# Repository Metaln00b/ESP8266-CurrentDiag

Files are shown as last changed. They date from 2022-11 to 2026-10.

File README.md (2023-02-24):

# ESP8266-CurrentDiag
ESP8266 (Wemos D1 mini) based Small Current Diagnostic Tool

Measure the current of the electro-hydraulic pressure regulator of a KE-Jetronic

Additionally the lambda value can be measured via the analog input if the gauge has a 5v output. For this, a 180k Ohm resistor must be connected in series before the A0.

I am using the *AFR Wideband Kit from DepoRacing with an OLED 52772WBOLED*

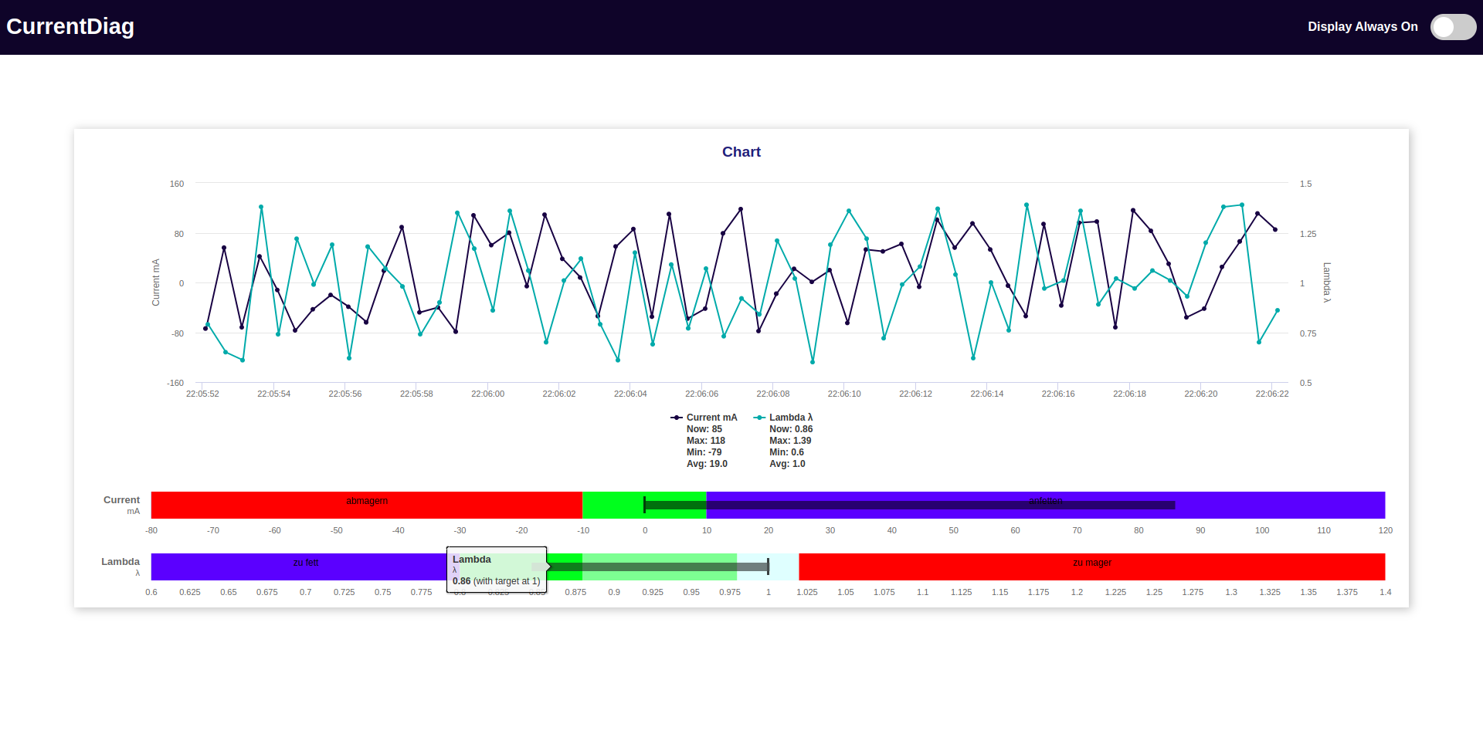
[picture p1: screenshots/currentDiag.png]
Web GUI


Lastly, I added a UDP connection, which transmits the values at a higher update rate, compared to the WebGui. For this I use a RaspberryPi Pico W with an Adafruit library for CircuitPython 8.0.3. The ESP8266 is the server and the Pico W is the client.

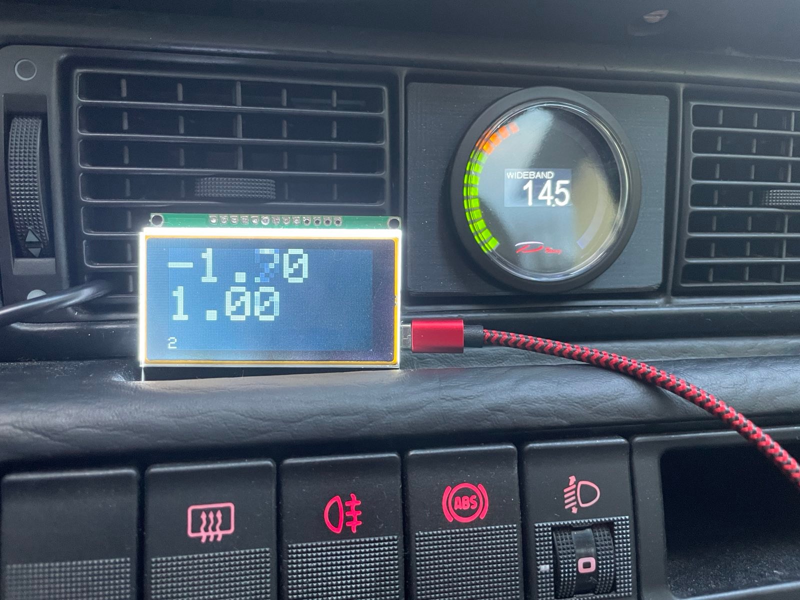
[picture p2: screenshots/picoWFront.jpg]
Pico W UDP Front


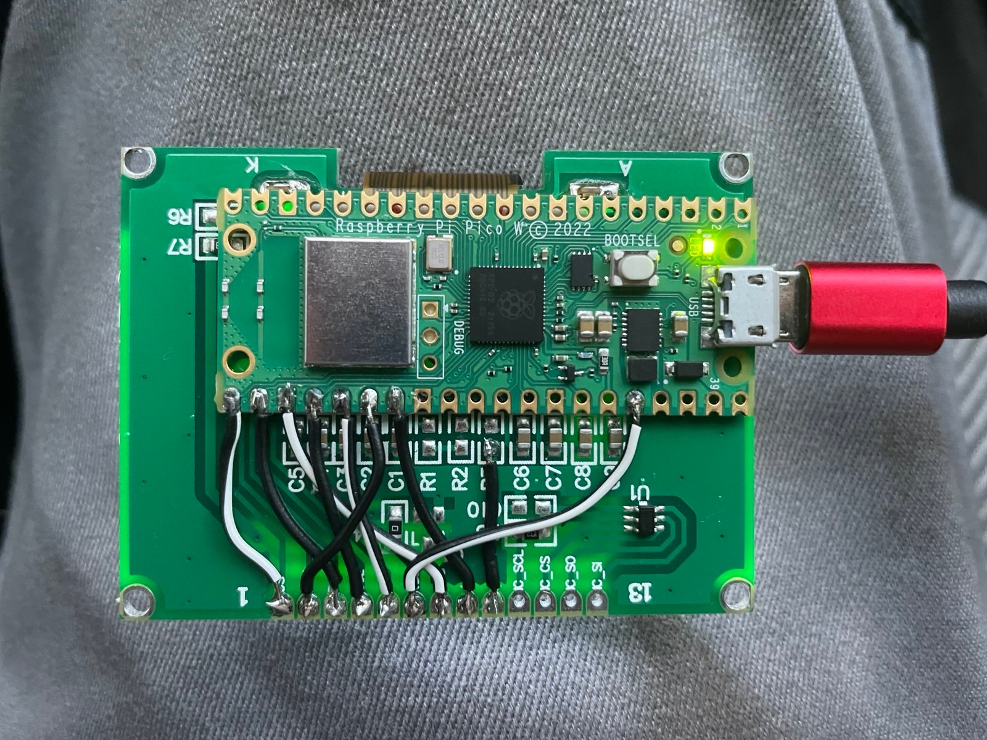
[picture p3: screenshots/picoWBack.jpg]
Pico W UDP Back


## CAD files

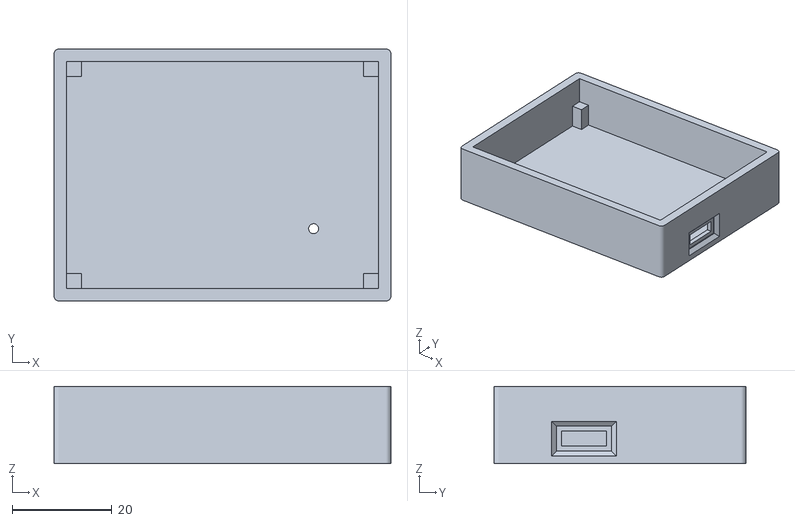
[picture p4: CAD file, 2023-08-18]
pico_w/CAD/CurrentDiag-Body.stl
67.5 x 50.5 x 15.5

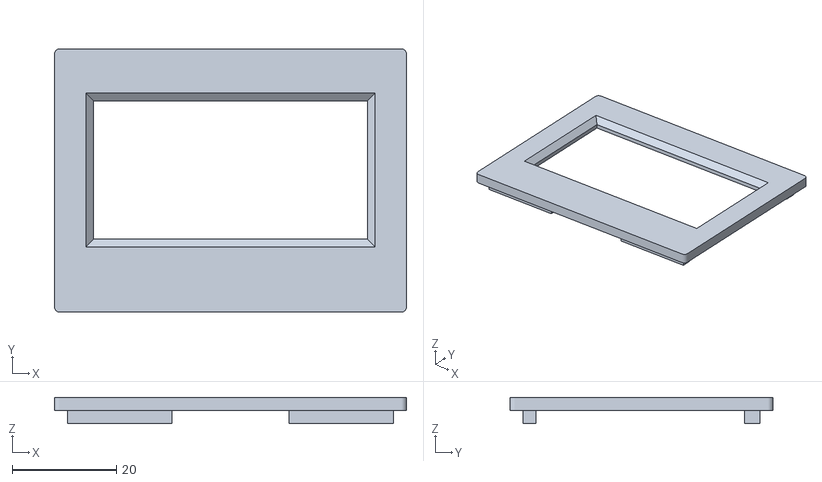
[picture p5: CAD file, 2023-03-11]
pico_w/CAD/CurrentDiag-Front.stl
67.5 x 50.5 x 5.00

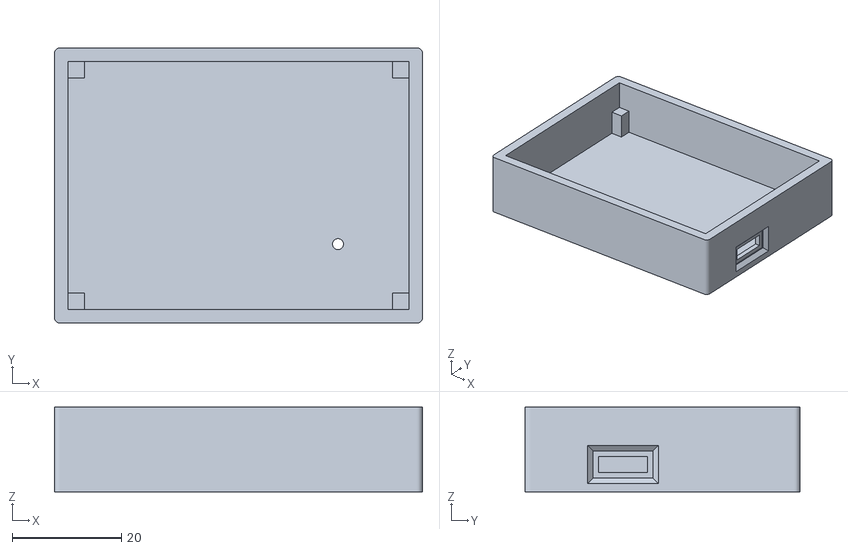
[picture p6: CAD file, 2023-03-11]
pico_w/CAD/CurrentDiag-Body_fixed.stl
67.5 x 50.5 x 15.5

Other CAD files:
pico_w/CAD/CurrentDiag.FCStd

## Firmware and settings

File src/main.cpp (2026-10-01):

#include "Wire.h"
#include "LittleFS.h"
#include "Adafruit_INA219.h"
#include <ESP8266WiFi.h>
#include <ESP8266WiFiAP.h>
#include <ESPAsyncTCP.h>
#include <ESPAsyncWebServer.h>
#include <ArduinoJson.h>
#include <ElegantOTA.h>
#include <WiFiUdp.h>


const char *ssid = "CurrentDiag";
const char *pass = "123456789";

AsyncWebServer server(80);
AsyncEventSource events("/events");

unsigned long lastWebTime = 0;
unsigned long lastUdpTime = 0;
unsigned long lastDataTime = 0;
unsigned long webTimerDelay = 250;
//unsigned long udpTimerDelay = 50;
unsigned long dataTimerDelay = 50;

#ifndef DEBUG
Adafruit_INA219 ina219;
#endif

IPAddress broadcastIP(192, 168, 4, 255);
constexpr uint16_t PORT = 8266;
char packetBuffer[255];
char sensorData[128];

WiFiUDP Udp;

// The ESP8266 SoftAP driver queues broadcast/multicast frames and only
// releases them aligned to its beacon/DTIM interval, regardless of the
// station's own sleep settings - that's what made UDP packets arrive at the
// receiver in ~300ms bursts instead of steadily. Sending unicast to the
// connected stations instead skips that batching. Every station gets its own
// copy, so several displays work at the same time. Falls back to broadcast
// until a station has actually connected.
constexpr uint8_t MAX_RECEIVERS = 4; // SoftAP station limit
IPAddress receivers[MAX_RECEIVERS];
volatile uint8_t receiverCount = 0;

// Samples collected since the last web event, e.g. "[1.00,0.90],[2.00,0.91],"
// The browser gets them in one batch so the chart keeps full resolution
// while it only has to redraw a few times per second.
constexpr size_t BATCH_SIZE = 640;
char webBatch[BATCH_SIZE];
size_t webBatchLen = 0;

void getSensorReadings(char *output, size_t outputSize)
{
    StaticJsonDocument<64> readings;
#ifndef DEBUG
    float current_mA = ina219.getCurrent_mA();
    // Values from afr gauge documentation
    // minLambda = 0.683 (and offset)
    // maxLambda = 1.356
    // lambdaRange = 0.673
    // adcRange = 1024 (0 - 5V with 180k resistor) 0.0049/V
    // 0.673 / 1024 = 0.000657227
    float lambda = ((analogRead(A0) * 0.000657227) + 0.683);
#else
    // Endless cycle: full min -> max -> min sweep, then 5s of random values
    constexpr float CURRENT_MIN = -80.0, CURRENT_MAX = 120.0;
    constexpr float LAMBDA_MIN = 0.6, LAMBDA_MAX = 1.3;
    constexpr unsigned long SWEEP_MS = 20000;
    constexpr unsigned long RANDOM_MS = 5000;
    static bool sweeping = true;
    static unsigned long phaseStart = millis();

    unsigned long elapsed = millis() - phaseStart;
    float current_mA;
    float lambda;

    if (sweeping)
    {
        if (elapsed >= SWEEP_MS)
        {
            sweeping = false;
            phaseStart = millis();
        }
        float frac = (elapsed >= SWEEP_MS) ? 1.0 : (float)elapsed / SWEEP_MS;
        float tri = (frac < 0.5) ? frac * 2.0 : (1.0 - frac) * 2.0; // 0 -> 1 -> 0
        current_mA = CURRENT_MIN + tri * (CURRENT_MAX - CURRENT_MIN);
        lambda = LAMBDA_MIN + tri * (LAMBDA_MAX - LAMBDA_MIN);
    }
    else
    {
        if (elapsed >= RANDOM_MS)
        {
            sweeping = true;
            phaseStart = millis();
        }
        current_mA = random(-80, 120);
        lambda = random(6, 14) / 10.0;
    }
#endif
    char sensor1ValueStr[10];
    char sensor2ValueStr[10];
    dtostrf(current_mA, 6, 2, sensor1ValueStr);
    dtostrf(lambda, 3, 2, sensor2ValueStr);

    readings["sensor1"] = sensor1ValueStr;
    readings["sensor2"] = sensor2ValueStr;

    serializeJson(readings, output, outputSize);

    // Append to web batch, drop the sample if the browser isn't keeping up
    int n = snprintf(webBatch + webBatchLen, BATCH_SIZE - webBatchLen, "[%s,%s],",
                     sensor1ValueStr, sensor2ValueStr);
    if (n > 0 && webBatchLen + n < BATCH_SIZE)
        webBatchLen += n;
}

void sendUdp(const char *data)
{
    uint8_t count = receiverCount;
    if (count == 0)
    {
        Udp.beginPacket(broadcastIP, PORT);
        Udp.print(data);
        Udp.endPacket();
        return;
    }

    for (uint8_t i = 0; i < count; i++)
    {
        Udp.beginPacket(receivers[i], PORT);
        Udp.print(data);
        Udp.endPacket();
    }
}

void initLittleFS()
{
    if (!LittleFS.begin())
    {
        Serial.println(F("An error has occurred while mounting LittleFS"));
    }
    else
    {
        Serial.println(F("LittleFS mounted successfully"));
    }
}

void showClients()
{
    unsigned char number_client;
    struct station_info *stat_info;

    struct ip4_addr *IPaddress;
    IPAddress address;
    int cnt = 1;

    number_client = wifi_softap_get_station_num();
    stat_info = wifi_softap_get_station_info();

    Serial.print(F("Connected clients: "));
    Serial.println(number_client);

    uint8_t count = 0;

    while (stat_info != NULL)
    {
        IPaddress = &stat_info->ip;
        address = IPaddress->addr;

        if (count < MAX_RECEIVERS)
            receivers[count++] = address;

        Serial.print(cnt);
        Serial.print(F(": IP: "));
        Serial.print((address));
        Serial.print(F(" MAC: "));

        uint8_t *p = stat_info->bssid;
        Serial.printf("%02X:%02X:%02X:%02X:%02X:%02X", p[0], p[1], p[2], p[3], p[4], p[5]);

        stat_info = STAILQ_NEXT(stat_info, next);
        cnt++;
        Serial.println();
    }

    receiverCount = count;
    wifi_softap_free_station_info(); // list is allocated by the SDK
}

void eventCb(System_Event_t *evt)
{
    switch (evt->event)
    {
    case WIFI_EVENT_SOFTAPMODE_DISTRIBUTE_STA_IP:
    case WIFI_EVENT_SOFTAPMODE_STADISCONNECTED:
        showClients();
        break;

    default:
        break;
    }
}

void initWiFi()
{
    Serial.println(F("Setting soft-AP ... "));
    wifi_set_event_handler_cb(eventCb);

    IPAddress apIP(192, 168, 4, 1);

    if (WiFi.softAPConfig(apIP, apIP, IPAddress(255, 255, 255, 0)))
        Serial.println(F("softAPConfig: True"));
    else
        Serial.println(F("softAPConfig: False"));

    if (WiFi.softAP(ssid, pass, 8))
        Serial.println(F("softAP: True"));
    else
        Serial.println(F("softAP: False"));

    IPAddress IP = WiFi.softAPIP();
    Serial.print(F("AP IP address: "));
    Serial.println(IP);
}

void setup()
{
    Serial.begin(115200);
    while (!Serial)
    {
        ; // Needed for native USB port only
    }
#ifndef DEBUG
    if (!ina219.begin())
    {
        Serial.println(F("Failed to find INA219 chip"));
    }
#endif

    initWiFi();
    initLittleFS();

    server.on("/", HTTP_GET, [](AsyncWebServerRequest *request)
              { request->send(LittleFS, "/index.html", "text/html"); });

    server.serveStatic("/", LittleFS, "/");

    events.onConnect([](AsyncEventSourceClient *client)
                     {
    if (client->lastId())
    {
      Serial.printf("Client reconnected! Last message ID that it got is: %u\n", client->lastId());
    }
    // send event with message "hello!", id current millis
    // and set reconnect delay to 1 second
    client->send("Hello!", NULL, millis(), 1000);
    Serial.println("Client connected!"); });

    server.addHandler(&events);

    ElegantOTA.begin(&server);

    server.begin();

    Udp.begin(PORT);

    getSensorReadings(sensorData, sizeof(sensorData));
}

void loop()
{
    unsigned long currentMillis = millis();

    if ((currentMillis - lastDataTime) > dataTimerDelay)
    {
        getSensorReadings(sensorData, sizeof(sensorData));
        sendUdp(sensorData);
        lastDataTime += dataTimerDelay;
    }

    if ((currentMillis - lastWebTime) > webTimerDelay)
    {
        // Skip the batch when the browsers can't keep up or the heap is low,
        // instead of piling up queued messages
        if (events.count() > 0 && webBatchLen > 0 && events.avgPacketsWaiting() < 4 && ESP.getFreeHeap() > 8000)
        {
            webBatch[webBatchLen - 1] = '\0'; // strip trailing comma
            char payload[BATCH_SIZE + 40];
            snprintf(payload, sizeof(payload), "{\"dt\":%lu,\"d\":[%s]}", dataTimerDelay, webBatch);
            events.send(payload, "new_readings", millis());
        }
        webBatchLen = 0;
        lastWebTime += webTimerDelay;
    }

    /* if ((currentMillis - lastUdpTime) > udpTimerDelay) {
      sendUdp(sensorData);
      lastUdpTime += udpTimerDelay;
    } */
    ElegantOTA.loop();

    yield();
}

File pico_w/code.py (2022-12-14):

# SPDX-FileCopyrightText: 2021 ladyada for Adafruit Industries
# SPDX-FileCopyrightText: 2021 Mark Olsson <mark@markolsson.se>
# SPDX-License-Identifier: MIT

import microcontroller
import board
import busio
import digitalio
import json
import socketpool
from st7565 import ST7565
import time
import wifi

EXDURATION = 2
TIMEOUT = 2
PORT = 8266

led_onboard = digitalio.DigitalInOut(board.LED)
led_onboard.direction = digitalio.Direction.OUTPUT

# Turn on the Backlight LED
backlight = digitalio.DigitalInOut(board.GP21)  # backlight
backlight.switch_to_output()
backlight.value = True

# Initialize SPI bus and control pins
spi = busio.SPI(clock=board.GP18, MOSI=board.GP19)
dc = digitalio.DigitalInOut(board.GP17)  # data/command
cs = digitalio.DigitalInOut(board.GP16)  # Chip select
reset = digitalio.DigitalInOut(board.GP20)  # reset

display = ST7565(spi, dc, cs, reset)
display.contrast = 3

reconnectCount = 0
heartBeat = True

v1Min = -80
v1Max = 120
v1Vline = 0

v2Min = 0.6
v2Max = 1.4
v2Vline = 1.0

def wrap(string, max_width):
    s=''
    for i in range(0,len(string),max_width):
        s+=string[i:i+max_width]
        s+='\n'
    return s

def printDisplay(string, duration_s):
    display.fill(0)
    display.text(wrap(string, 20), 0, 0, 1)
    display.show()
    time.sleep(duration_s)

def connectWifi():
    while True:
        try:
            wifi.radio.connect("CurrentDiag", "123456789")
            break
        except Exception as e:
            if (str(e) == "Unbekannter Fehler 1" ):
                microcontroller.reset()
            printDisplay(str(e), EXDURATION)

def drawValuebar(x, y, width, height, valueMin, valueMax, value, vlineValue, showNumbers):
    roundValue = round(value, 2)
    roundValue = max(min(valueMax, roundValue), valueMin)

    valueRange = valueMax - valueMin
    pxPerValue = (width - 4) / valueRange
    pxPositionVline = int(pxPerValue * (vlineValue - valueMin) + 2)
    
    pxPositionValue = int(pxPerValue * (roundValue - valueMin) + 2)
    start = min(pxPositionValue, pxPositionVline)
    end = max(pxPositionValue, pxPositionVline)

    display.rect(x, y, width, height, 1)
    display.fill_rect(x+start, y+2, end-start, height-4, 1) 
    
    if (height >= 15 and showNumbers):
        if (value >= vlineValue):
            display.text(str(f"{roundValue:.2f}"), int(width/9), y+5, 1, size=1)
        else:
            display.text(str(f"{roundValue:.2f}"), int(width/1.5), y+5, 1, size=1)
        
    display.vline(int(pxPositionVline), y-1, height+2, 1)

printDisplay("Connecting to wifi", 1)
connectWifi()

pool = socketpool.SocketPool(wifi.radio)
buff = bytearray(255)

printDisplay("Creating socket", 1)
socket = pool.socket(pool.AF_INET, pool.SOCK_DGRAM)
socket.settimeout(TIMEOUT)
printDisplay("Connecting", 1)
socket.bind((str(wifi.radio.ipv4_address), PORT))
printDisplay("Receiving", 1)

while True:
    while True:
        try:
            buff = bytearray(255)
            size, addr = socket.recvfrom_into(buff)
            break
        except Exception as e:
            printDisplay(str(e), EXDURATION)
            printDisplay("Try Reconnecting", 1)
            reconnectCount = reconnectCount+1
            socket.close()
            connectWifi()
            pool = socketpool.SocketPool(wifi.radio)
            socket = pool.socket(pool.AF_INET, pool.SOCK_DGRAM)
            socket.settimeout(TIMEOUT)
            socket.bind((str(wifi.radio.ipv4_address), PORT))
    
    msg = buff.decode('utf-8')
    try:
        data = json.loads(msg)
    except Exception as e:
        printDisplay(str(e), EXDURATION)
    
    display.fill(0)
    
    try:
        
        display.text("Actuator: " + data['sensor1'] + "mA", 0, 0, 1)
        drawValuebar(0, 10, 128, 12, v1Min, v1Max, float(data['sensor1']), v1Vline, False)
        display.text("Lambda: " + data['sensor2'], 0, 26, 1)
        drawValuebar(0, 36, 128, 12, v2Min, v2Max, float(data['sensor2']), v2Vline, False)
    except Exception as e:
        printDisplay(str(e), EXDURATION)

    heartBeat = not heartBeat
    #led_onboard.value = not led_onboard.value
    
    if (heartBeat):
        display.pixel(display.width - 1, display.height - 1, 1)
    
    #display.text(str(reconnectCount), 0, 56, 1)
    display.show()

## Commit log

2022-10-08 Add analog value 0-5V for lambda
2022-11-16 Add Raspberry Pico W code
2022-11-18 Optimize ErrorHandling and Timings
    [code.py, main.cpp]
2022-11-19 PicoW: Fix reconnection behaviour
    [code.py]
2022-11-22 PicoW: Reset if Unknown Error 1
    [code.py]
2023-02-24 PicoW: Update Circuit Python and libraries
2023-03-10 PicoW: Add FreeCAD Case
    [CurrentDiag.FCStd]
2023-03-11 PicoW: Add stl files
    [CurrentDiag-Body_fixed.stl, CurrentDiag-Front.stl, CurrentDiag.FCStd]
2023-07-04 ESP8266: Remove raise condition after website refresh, Use ArduinoJson and cleanup code
2023-08-18 PicoW: Change stl files
    [CurrentDiag-Body.stl]
2026-09-20 Send sensor UDP packets unicast to the known receiver instead of broadcast
    The ESP8266 SoftAP driver batches broadcast/multicast frames to its
    beacon/DTIM interval regardless of the station's sleep settings, which
    made packets arrive at the receiver in ~300ms bursts instead of a
    steady stream. Track the connected station's IP (already available via
    showClients()) and address sendUdp() directly to it, falling back to
    the old broadcast address until a station has connected.
2026-10-01 Send UDP to all connected stations, batch web events, fix station info leak
    - Unicast the sensor packets to every connected station (max 4) so several
    displays work, broadcast until a station has connected
    - Free the SDK station list in showClients()
    - Collect samples and send them as one batched SSE event every 250ms, only
    while a browser is connected
    - SSE reconnect delay 1s, drop unused /readings route
    - DEBUG: sweep min->max->min, then 5s of random values, repeated
    [main.cpp]
2026-10-01 Rework web interface: smooth scrolling chart, controls, dark mode
    - Chart scrolls with the clock and gets batched samples, no per-sample redraws
    - Pause, time window, CSV export of the in-browser log, dark mode
    - Stats and big readouts instead of the legend, connection status
    - Wake lock waits for success and is re-acquired after tab switch
    - Fix viewport meta and missing charset
2026-10-01 Fix crash on SSE client disconnect, add backpressure and heap log
    ESPAsyncWebServer 3.6.0 erases from the client list without break in
    AsyncEventSource::_handleDisconnect and then increments the erased iterator,
    which crashed the ESP when a browser closed its event stream (e.g. page
    refresh). Update to 3.8.0.
    Also skip a web batch when browsers can't keep up or heap is low, and log
    free heap every 5 s.
    [main.cpp]
2026-10-01 Web UI: icon toolbar, dark mode switch, always-on off by default
    - Pause/time window/CSV on the chart card with icons, dark mode as switch
    - Always on is off by default and not stored, browsers need a user gesture
    - Fix switch that could not be turned off
